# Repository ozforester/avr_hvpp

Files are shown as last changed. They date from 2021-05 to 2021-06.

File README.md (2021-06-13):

# avr_hvpp

Simple hvpp programmer on atmega8 and 1602A lcd with twi extention<br>

Kicad schematics and pcb's are placed in hardware folder.
Sure you can even plug mega328 into master socket and<br>
write your code in arduino ide and modify pcb for another package.<br>
Kicad is the most useful tool to change things you like<br>

I'm thinking about coding main menu in C and others: <br>
lcd, twi, adc and hvpp libraries in assembly.<br>
Pure C version I coded was compiled to 8k (w/o a few bytes)<br>
Assembly version is changing now. If you need test one working<br>
You can find a hex file named chiphealer.hex on hardware folder.<br>
Some more errors has to be fixed and I may commit its gas version too<br>

All work except kicad were processed on orange pc.<br>
It's very hard to edit pcb and schematics on orange<br>
(opengl works and 3d model turns but don't do that,<br>
really, beleve me)

And more. I'm learning now. Doing a lot of compromised<br>
steps in programming. These are like a practical answers<br>
to some questions and thus not perfect<br>

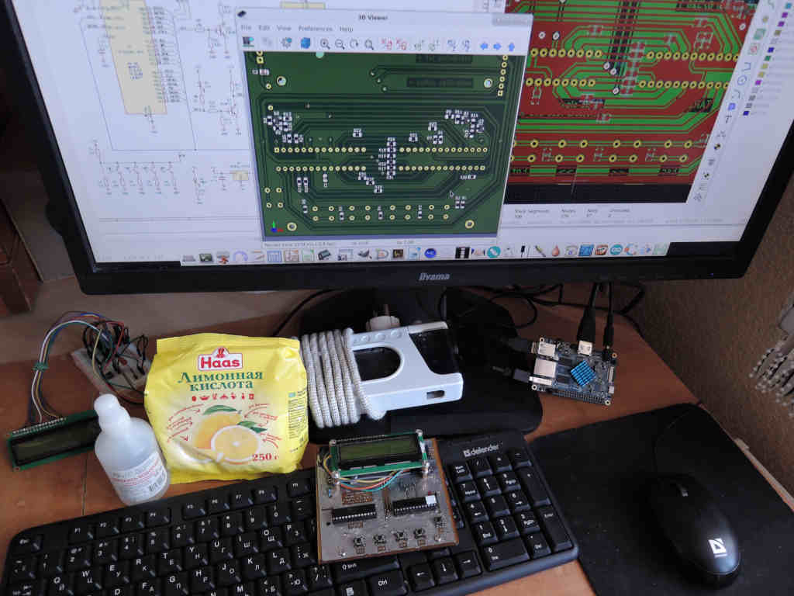
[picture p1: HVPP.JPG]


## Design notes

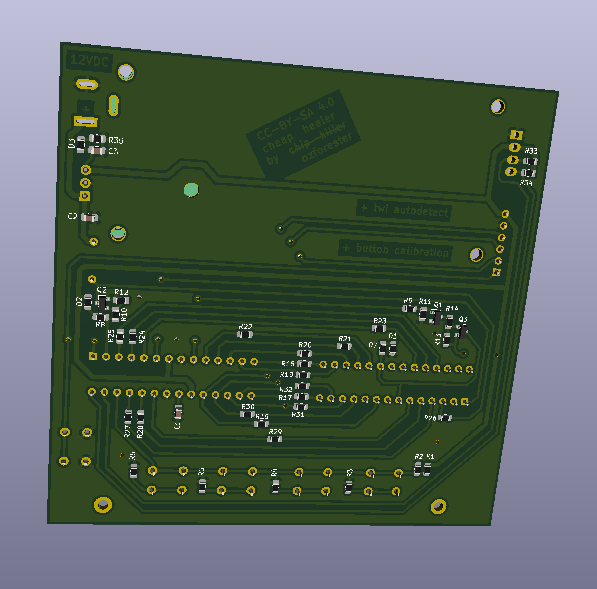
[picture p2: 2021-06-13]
hardware/3d-bottom.png

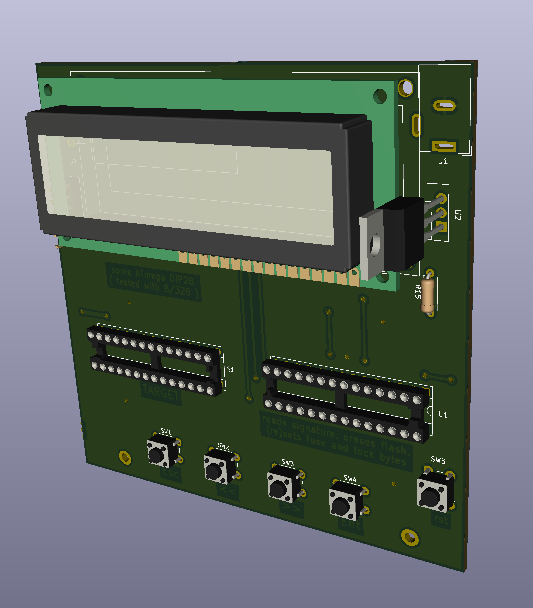
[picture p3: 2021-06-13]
hardware/3d-top.png

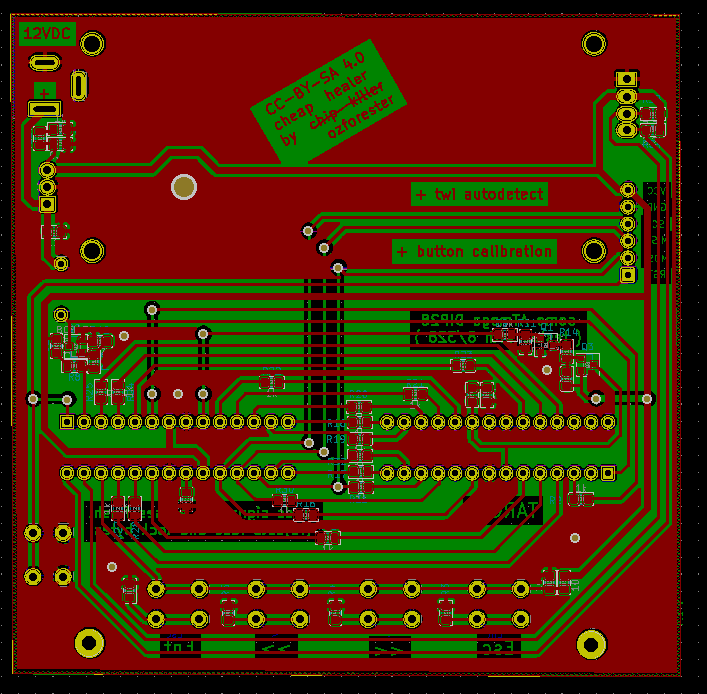
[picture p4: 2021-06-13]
hardware/pcb-bottom.png

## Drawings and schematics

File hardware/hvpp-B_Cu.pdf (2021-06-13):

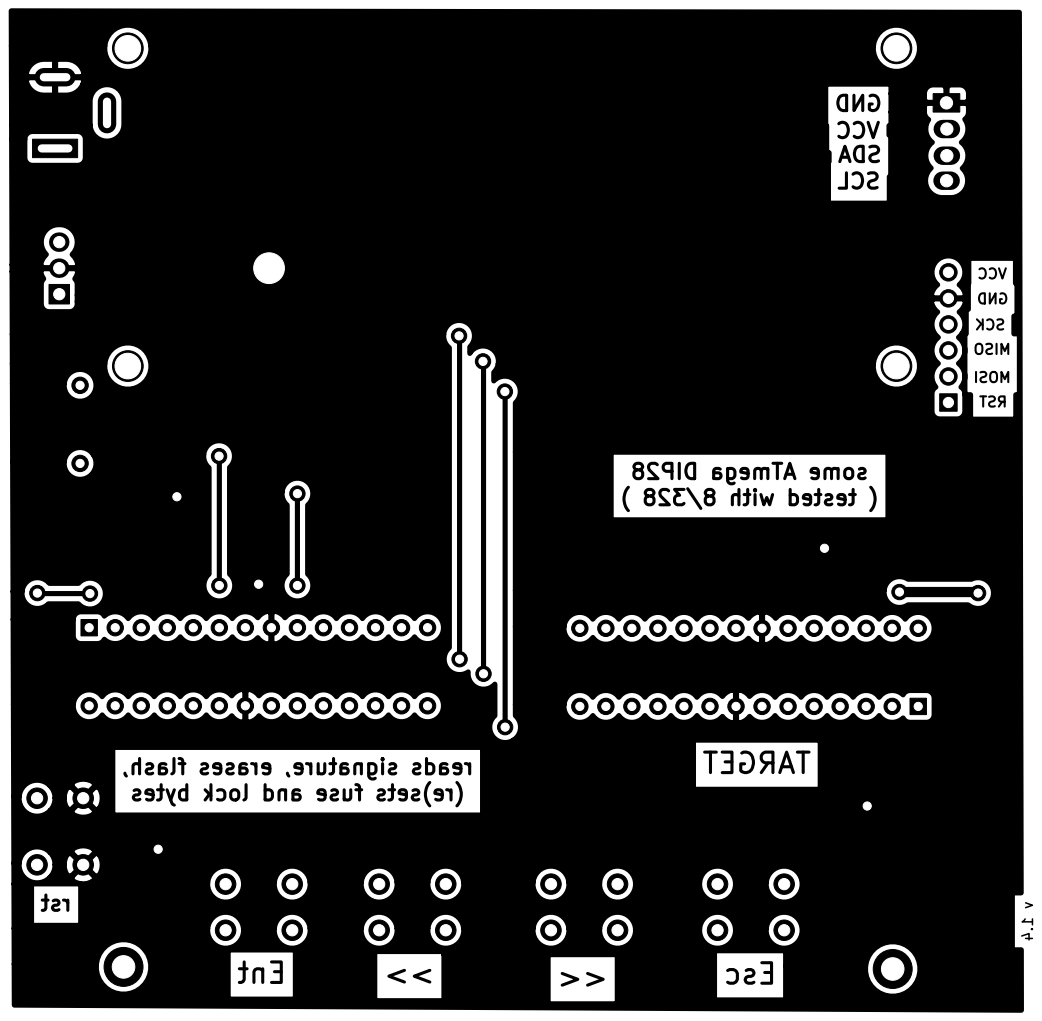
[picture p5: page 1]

(re)sets fuse and lock bytes GND

SCK MISO MOSI v 1.4 rst reads signature, erases flash,

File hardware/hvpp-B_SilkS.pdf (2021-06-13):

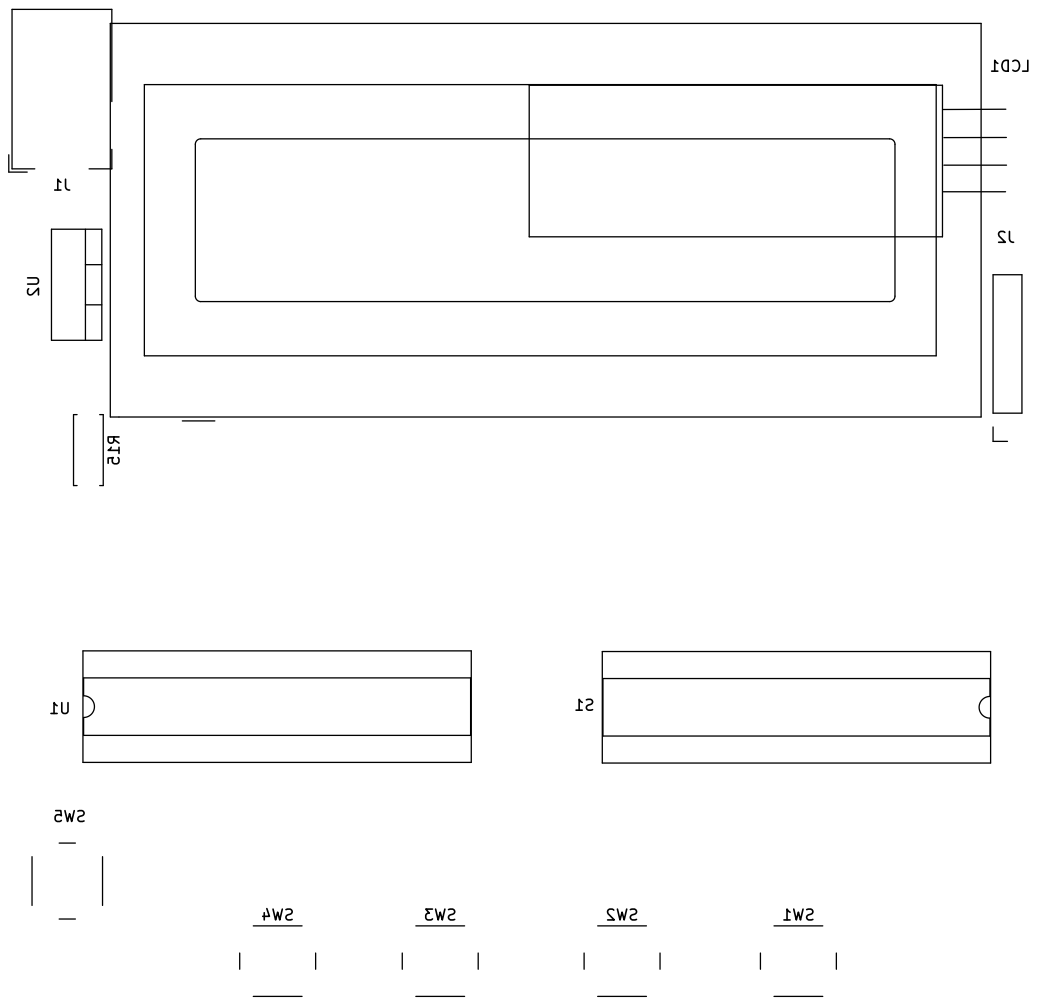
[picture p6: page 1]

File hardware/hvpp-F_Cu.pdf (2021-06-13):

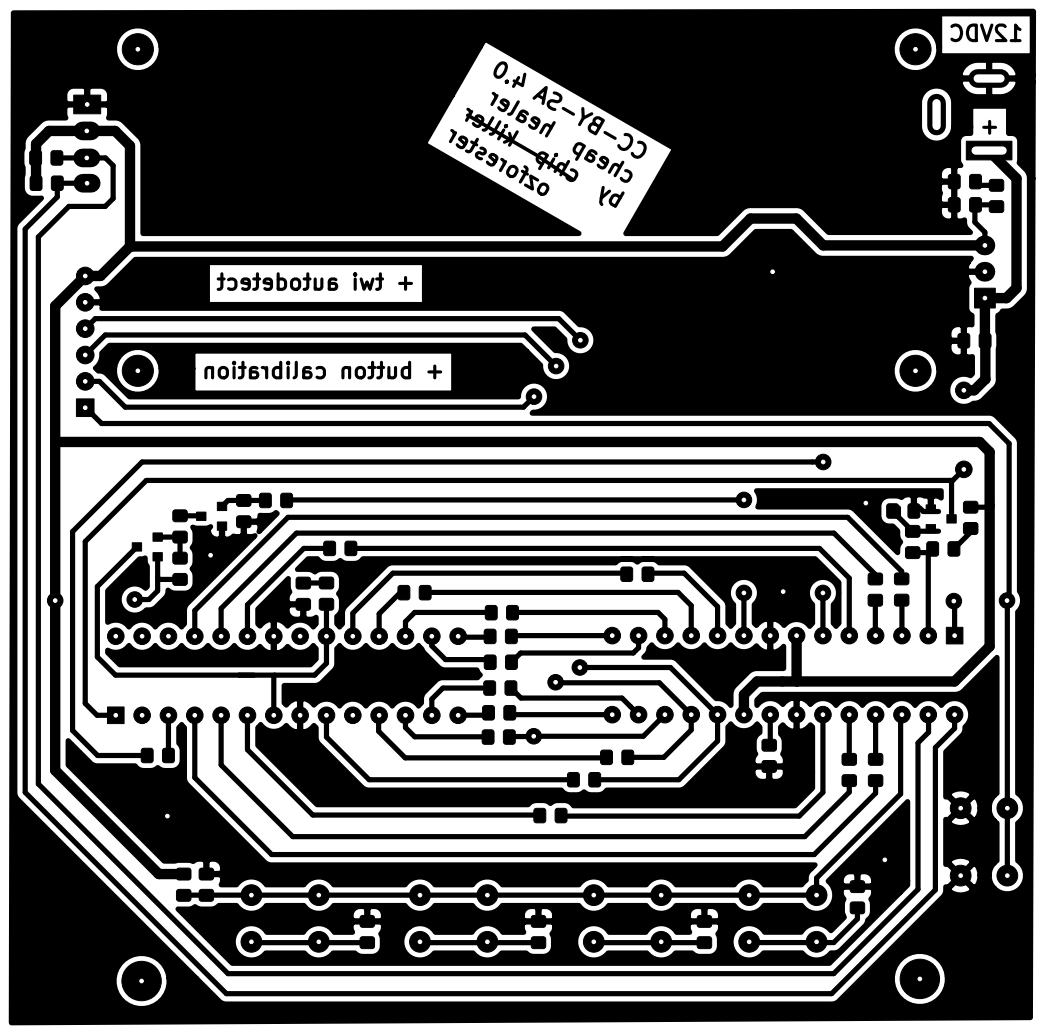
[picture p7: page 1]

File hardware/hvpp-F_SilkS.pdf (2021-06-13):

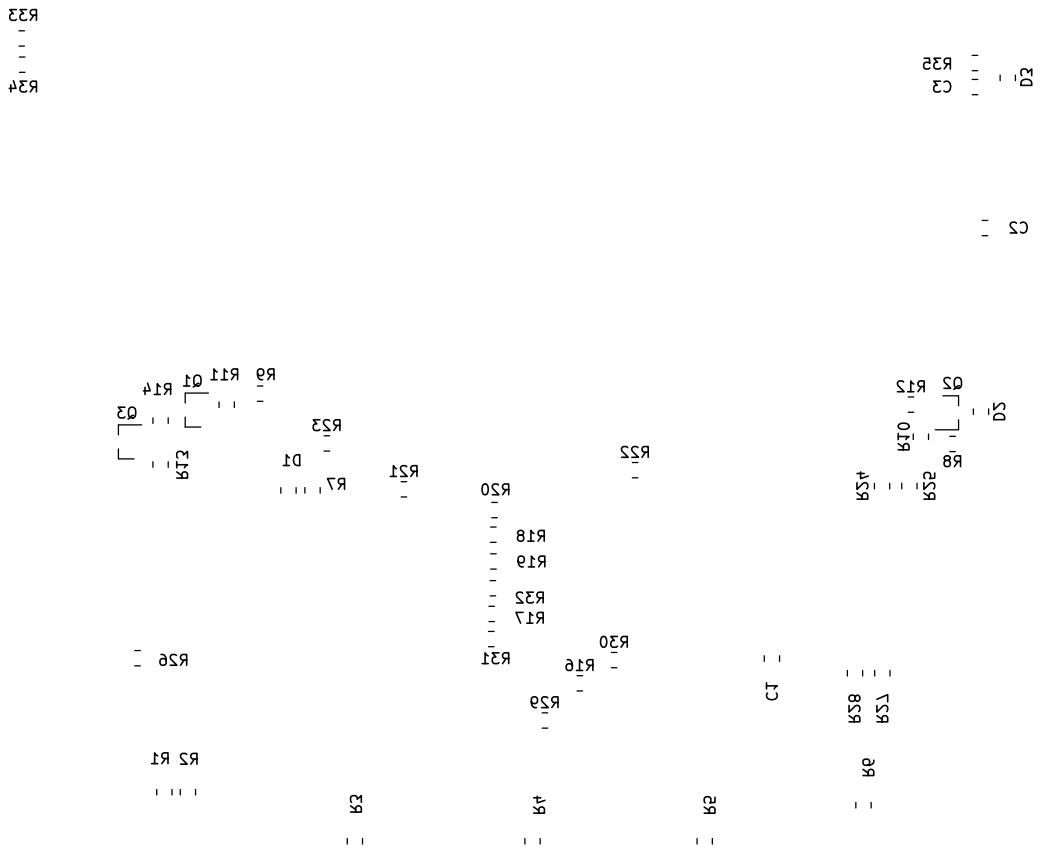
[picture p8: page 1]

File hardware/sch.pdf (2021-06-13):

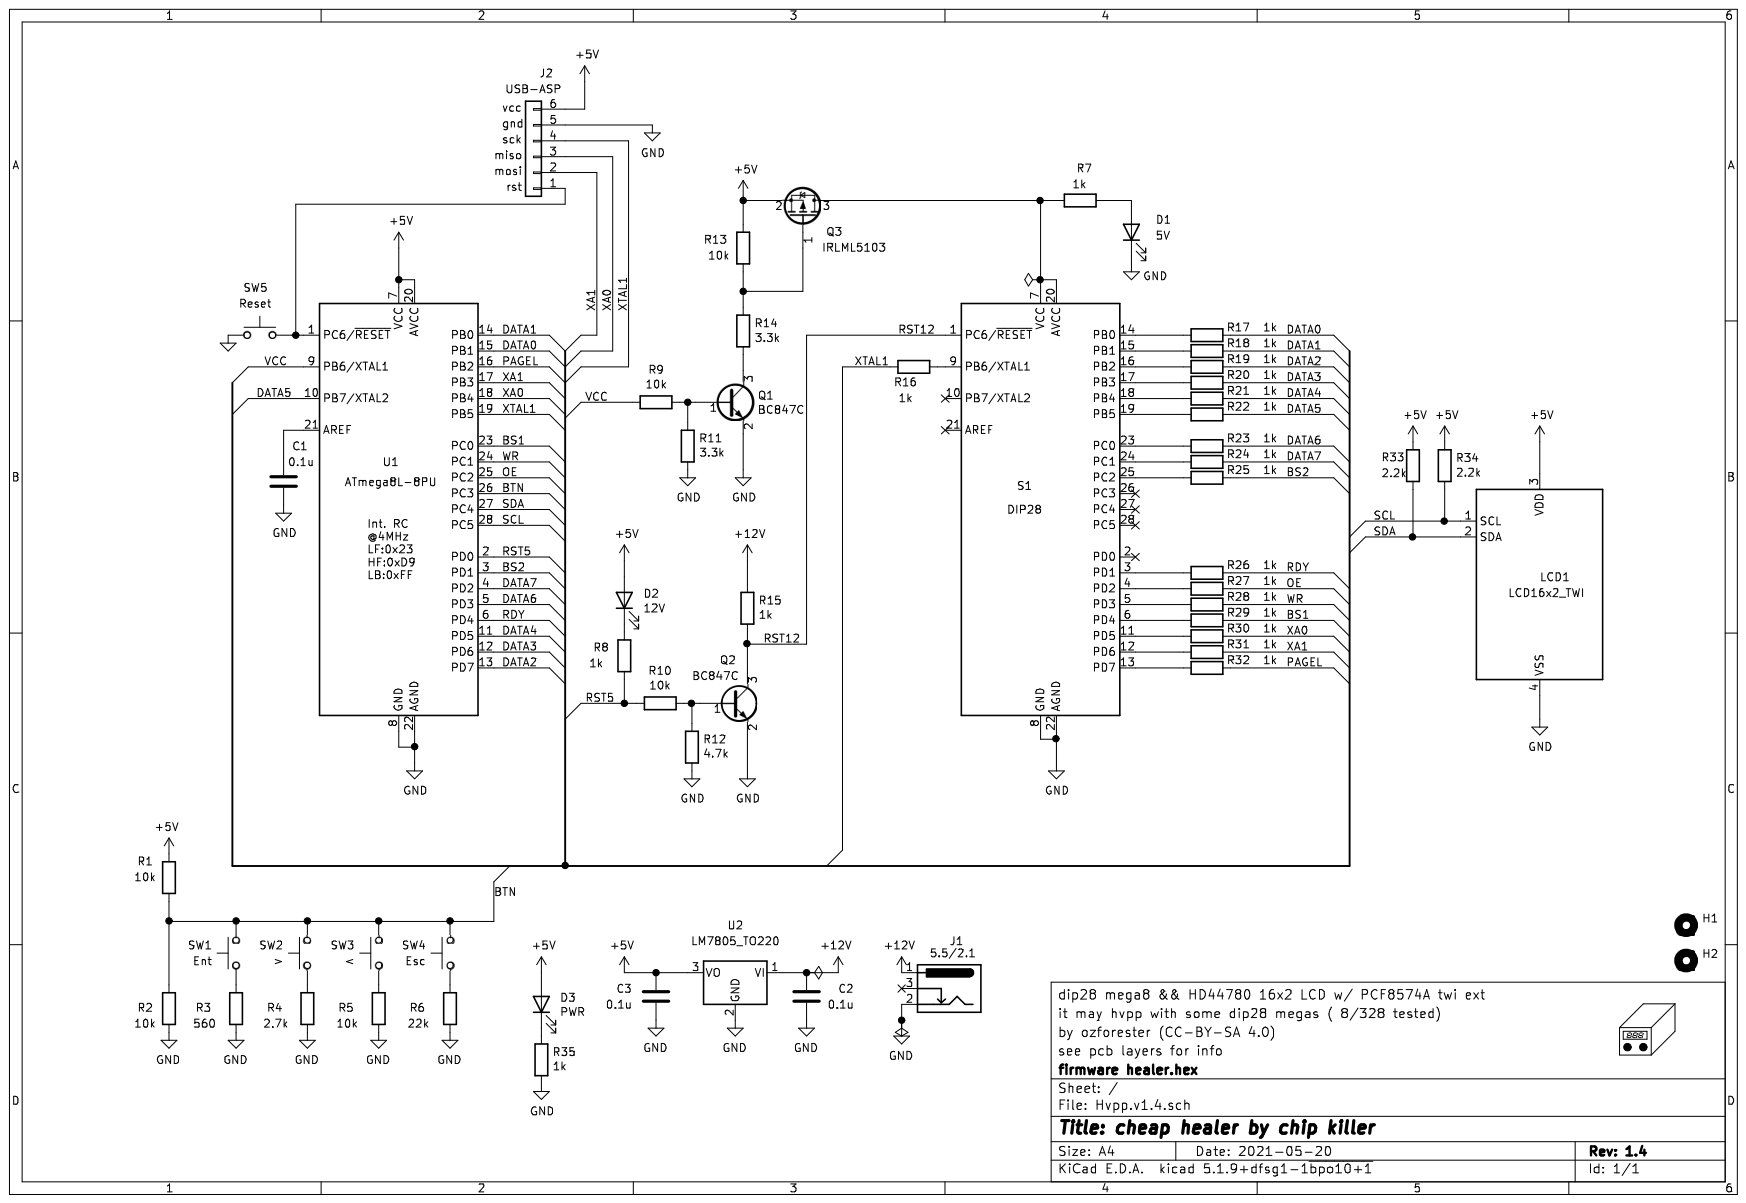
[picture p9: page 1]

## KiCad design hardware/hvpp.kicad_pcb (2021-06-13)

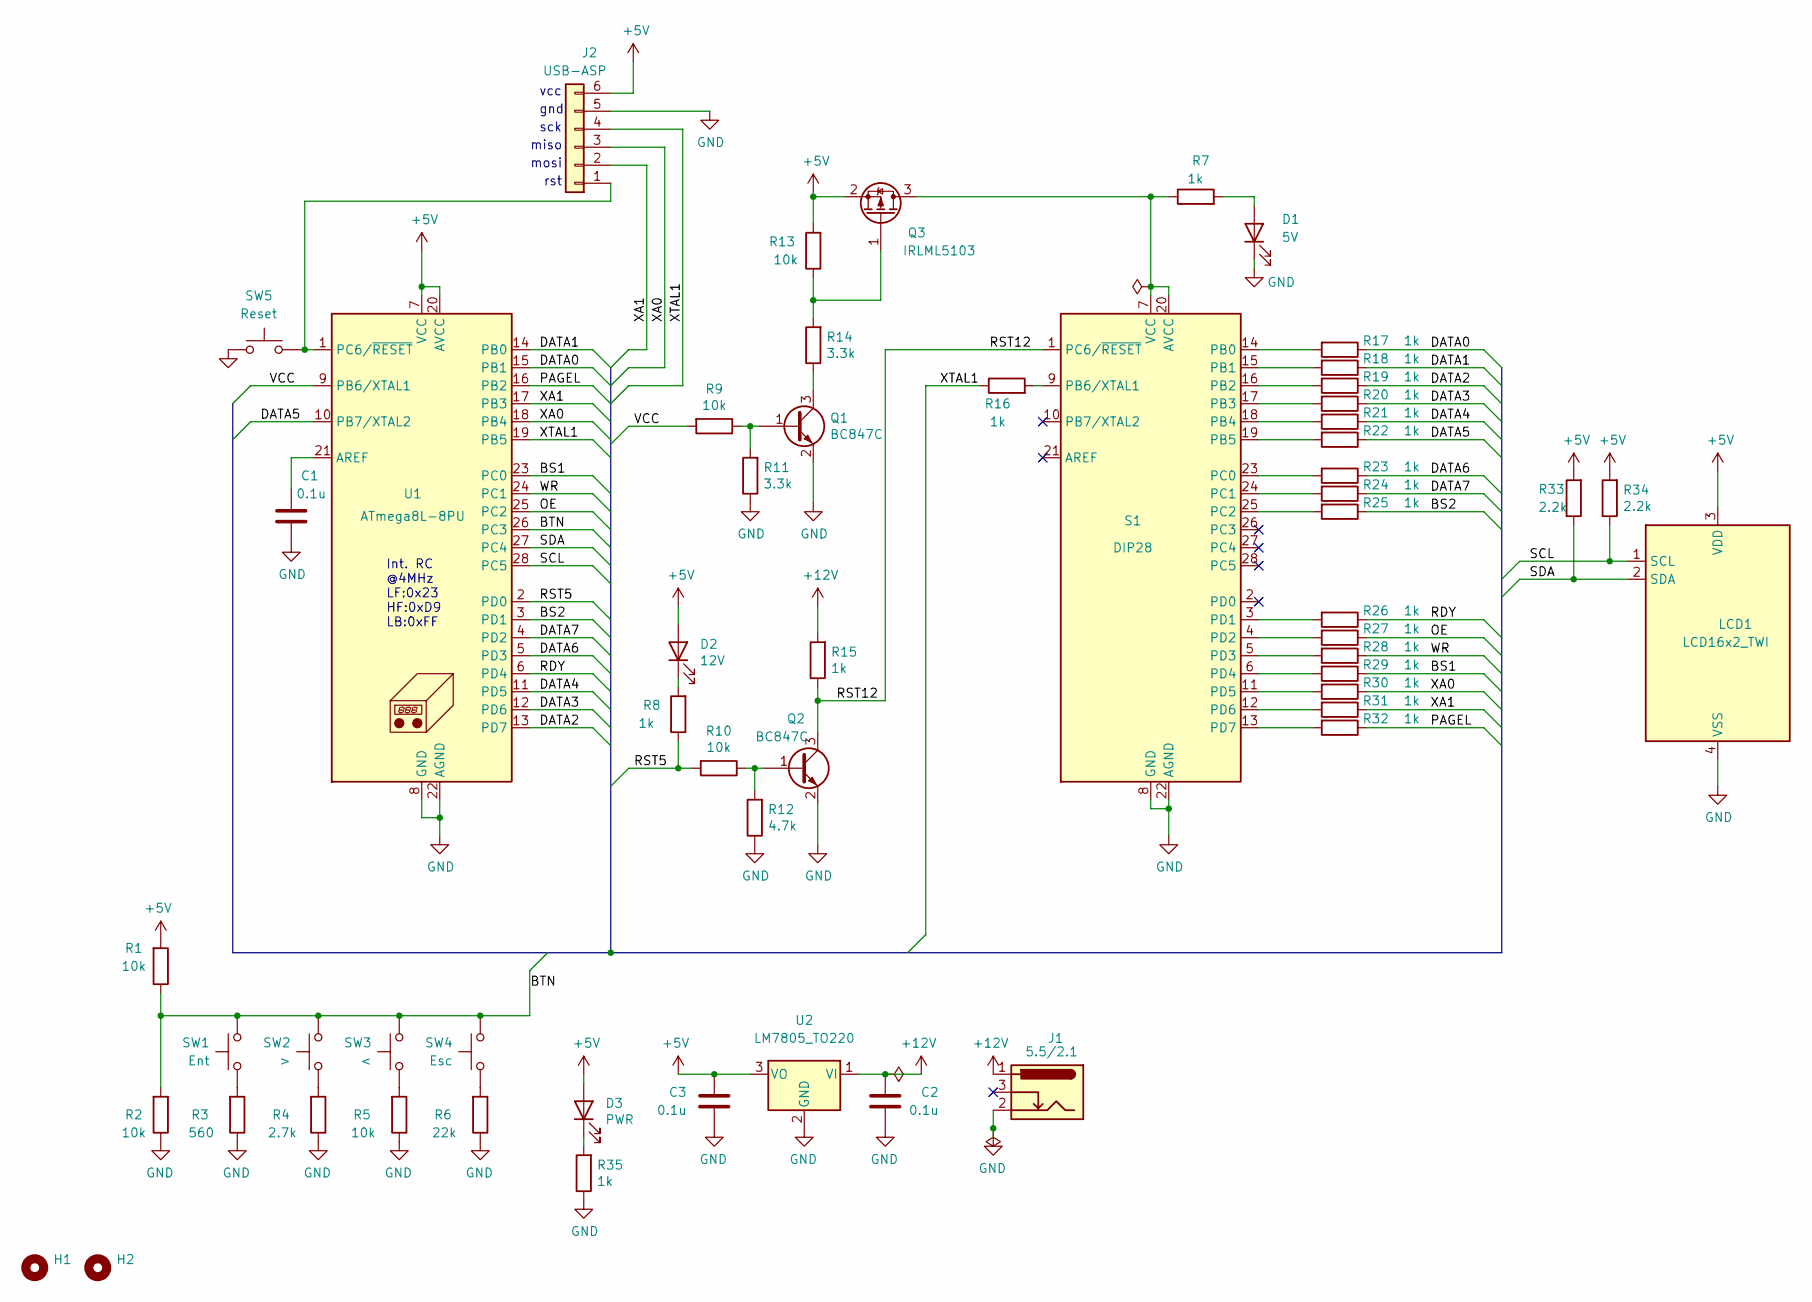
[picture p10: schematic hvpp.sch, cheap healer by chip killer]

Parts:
C1, C2, C3: 0.1u; C_0805_2012Metric_Pad1.15x1.40mm_HandSolder
D1: 5V; R_0805_2012Metric_Pad1.15x1.40mm_HandSolder
D2: 12V; R_0805_2012Metric_Pad1.15x1.40mm_HandSolder
D3: PWR; R_0805_2012Metric_Pad1.15x1.40mm_HandSolder
H1, H2: MountingHole; MountingHole_2.2mm_M2_DIN965_Pad
J1: 5.5/2.1; barreljack
J2: USB-ASP; PinHeader_1x06_P2.54mm_Vertical
LCD1: LCD16x2_TWI; 1602A
N1: Housing; DIP-28_W7.62mm
Q1, Q2: BC847C; SOT-23
Q3: IRLML5103; SOT-23
R1, R2, R5, R9, R10, R13: 10k; R_0805_2012Metric_Pad1.15x1.40mm_HandSolder
R3: 560; R_0805_2012Metric_Pad1.15x1.40mm_HandSolder
R4: 2.7k; R_0805_2012Metric_Pad1.15x1.40mm_HandSolder
R6: 22k; R_0805_2012Metric_Pad1.15x1.40mm_HandSolder
R7, R8, R16, R17, R18, R19, R20, R21, R22, R23, R24, R25, R26, R27, R28, R29, R30, R31, R32, R35: 1k; R_0805_2012Metric_Pad1.15x1.40mm_HandSolder
R11, R14: 3.3k; R_0805_2012Metric_Pad1.15x1.40mm_HandSolder
R12: 4.7k; R_0805_2012Metric_Pad1.15x1.40mm_HandSolder
R15: 1k; R_Axial_DIN0207_L6.3mm_D2.5mm_P7.62mm_Horizontal
R33, R34: 2.2k; R_0805_2012Metric_Pad1.15x1.40mm_HandSolder
S1: DIP28; DIP-28_W7.62mm_Socket
SW1: Ent; SW_PUSH_6mm_H5mm
SW2: >; SW_PUSH_6mm_H5mm
SW3: <; SW_PUSH_6mm_H5mm
SW4: Esc; SW_PUSH_6mm_H5mm
SW5: Reset; SW_PUSH_6mm_H5mm
U1: ATmega8L-8PU; DIP-28_W7.62mm_Socket
U2: LM7805_TO220; TO-220-3_Vertical

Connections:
+5V: C3.1, D2.2 (A), D3.2 (A), J2.6, LCD1.3 (VDD), Q3.2 (S), R1.2, R13.2, R33.2, R34.2, U1.7 (VCC), U1.20 (AVCC), U2.3 (VO)
+12V: C2.1, J1.1, R15.2, U2.1 (VI)
/BS1: R29.1, U1.23 (PC0)
/BS2: R25.1, U1.3 (PD1)
/BTN: R1.1, R2.2, SW1.1, SW2.1, SW3.1, SW4.1, U1.26 (PC3)
/DATA0: R17.1, U1.15 (PB1)
/DATA1: R18.1, U1.14 (PB0)
/DATA2: R19.1, U1.13 (PD7)
/DATA3: R20.1, U1.12 (PD6)
/DATA4: R21.1, U1.11 (PD5)
/DATA5: R22.1, U1.10 (PB7/XTAL2)
/DATA6: R23.1, U1.5 (PD3)
/DATA7: R24.1, U1.4 (PD2)
/OE: R27.1, U1.25 (PC2)
/PAGEL: R32.1, U1.16 (PB2)
/RDY: R26.1, U1.6 (PD4)
/RST5: R8.1, R10.2, U1.2 (PD0)
/RST12: Q2.3 (C), R15.1, S1.1 (PC6/~RESET)
/SCL: LCD1.1 (SCL), R34.1, U1.28 (PC5)
/SDA: LCD1.2 (SDA), R33.1, U1.27 (PC4)
/VCC: R9.2, U1.9 (PB6/XTAL1)
/WR: R28.1, U1.24 (PC1)
/XA0: J2.3, R30.1, U1.18 (PB4)
/XA1: J2.2, R31.1, U1.17 (PB3)
/XTAL1: J2.4, R16.1, U1.19 (PB5)
GND: C1.2, C2.2, C3.2, D1.1 (K), J1.2, J2.5, LCD1.4 (VSS), Q1.2 (E), Q2.2 (E), R2.1, R3.1, R4.1, R5.1, R6.1, R11.1, R12.1, R35.1, S1.8 (GND), S1.22 (AGND), SW5.2, U1.8 (GND), U1.22 (AGND), U2.2 (GND)
unnamed: C1.1, U1.21 (AREF)
unnamed: D1.2 (A), R7.2
unnamed: D2.1 (K), R8.2
unnamed: D3.1 (K), R35.2
unnamed: J2.1, SW5.1, U1.1 (PC6/~RESET)
unnamed: Q1.1 (B), R9.1, R11.2
unnamed: Q1.3 (C), R14.1
unnamed: Q2.1 (B), R10.1, R12.2
unnamed: Q3.1 (G), R13.1, R14.2
unnamed: Q3.3 (D), R7.1, S1.7 (VCC), S1.20 (AVCC)
unnamed: R3.2, SW1.2
unnamed: R4.2, SW2.2
unnamed: R5.2, SW3.2
unnamed: R6.2, SW4.2
unnamed: R16.2, S1.9 (PB6/XTAL1)
unnamed: R17.2, S1.14 (PB0)
unnamed: R18.2, S1.15 (PB1)
unnamed: R19.2, S1.16 (PB2)
unnamed: R20.2, S1.17 (PB3)
unnamed: R21.2, S1.18 (PB4)
unnamed: R22.2, S1.19 (PB5)
unnamed: R23.2, S1.23 (PC0)
unnamed: R24.2, S1.24 (PC1)
unnamed: R25.2, S1.25 (PC2)
unnamed: R26.2, S1.3 (PD1)
unnamed: R27.2, S1.4 (PD2)
unnamed: R28.2, S1.5 (PD3)
unnamed: R29.2, S1.6 (PD4)
unnamed: R30.2, S1.11 (PD5)
unnamed: R31.2, S1.12 (PD6)
unnamed: R32.2, S1.13 (PD7)

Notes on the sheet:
mosi
miso
sck
gnd
vcc
rst
Int. RC @4MHz LF:0x23 HF:0xD9 LB:0xFF

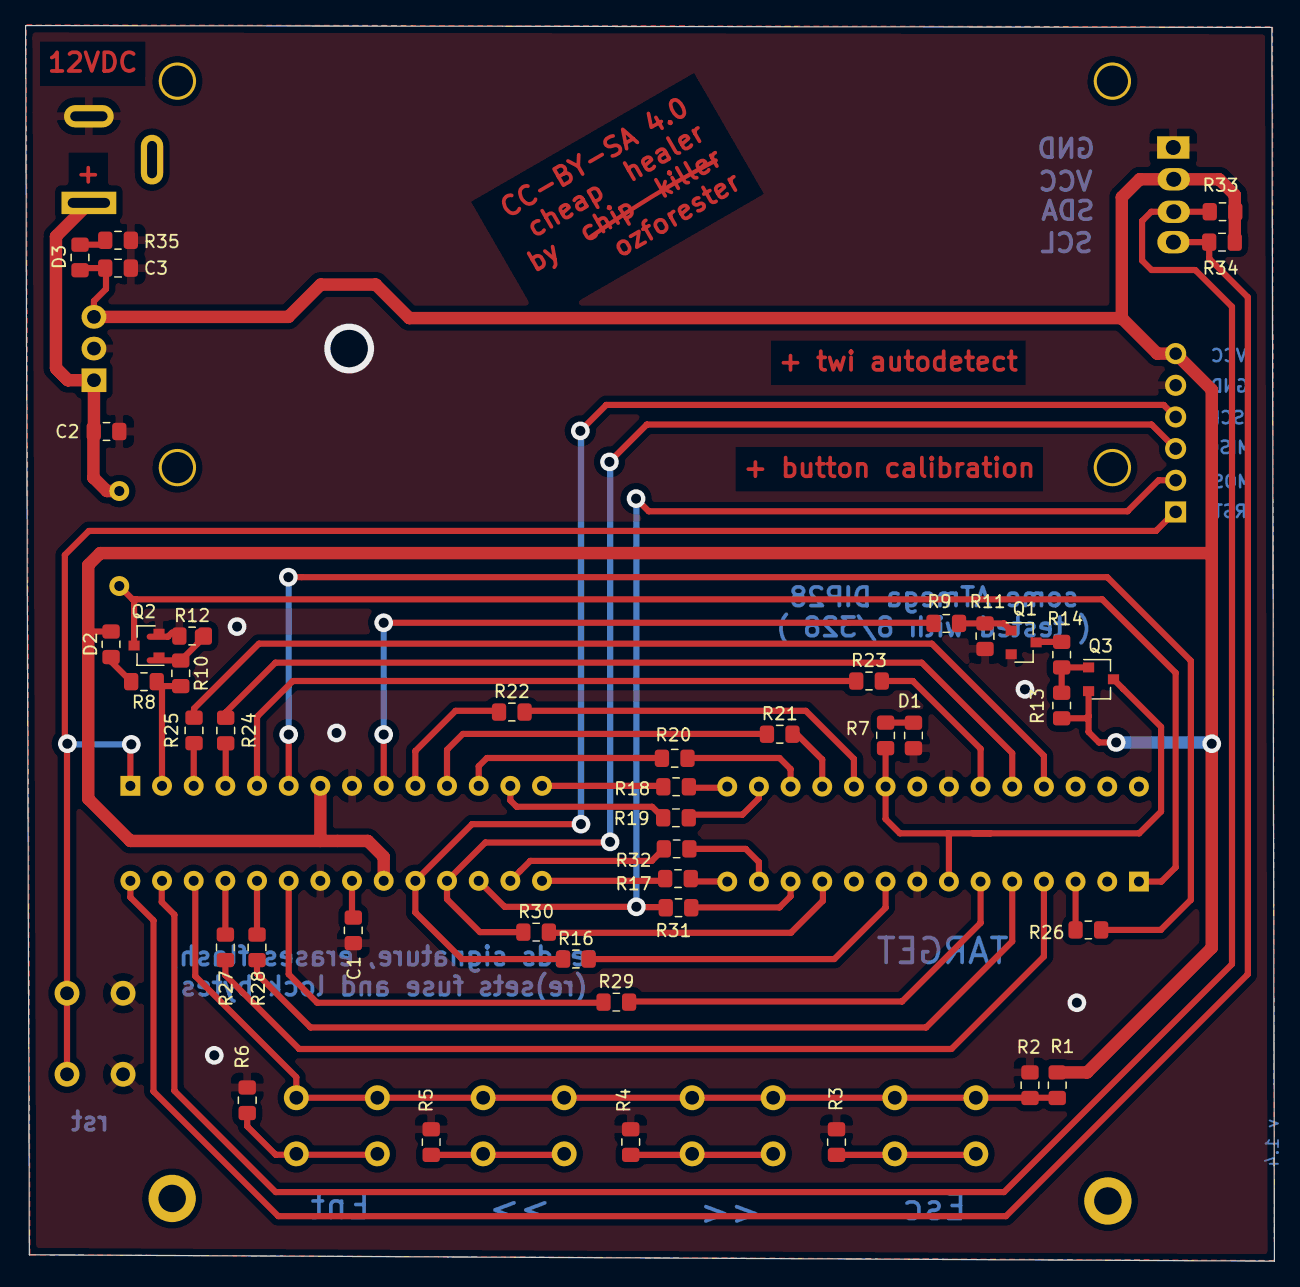
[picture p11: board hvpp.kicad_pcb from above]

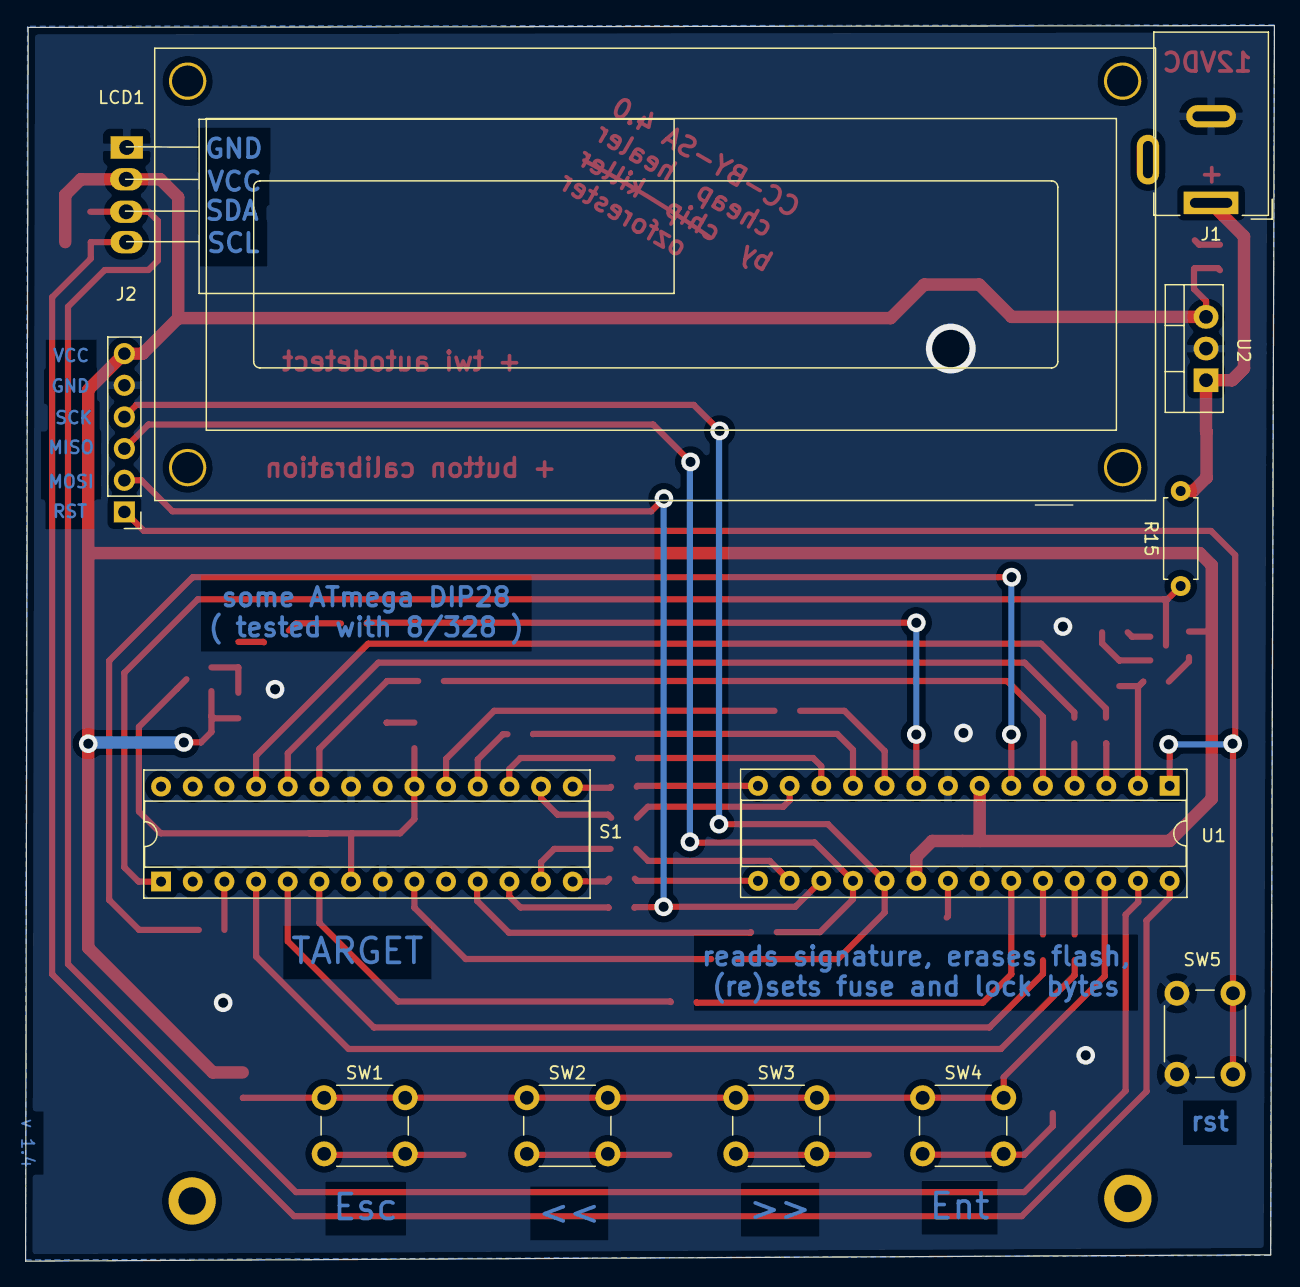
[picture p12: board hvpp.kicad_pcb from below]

Board: 2 copper layers, 100.2 x 99.1 mm, 57 parts (12 on the bottom side), 57 nets.

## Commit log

2021-06-06 pure assembly version
2021-06-12 a little time to work
    [hvpp.kicad_pcb]

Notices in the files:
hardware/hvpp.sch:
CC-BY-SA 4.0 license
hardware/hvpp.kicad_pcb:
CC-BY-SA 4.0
